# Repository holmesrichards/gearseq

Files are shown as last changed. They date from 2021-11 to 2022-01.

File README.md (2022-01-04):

# G.E.A.R. Sequencer

This is a voltage controlled trigger sequencer or, perhaps a better term, trigger sequence generator. It can function as a Euclidean rhythm generator, but it can also create other rhythms via different means. It is designed in Kosmo format, though it can presumably be adapted to any other format capable of supplying enough positive voltage for 5 V voltage regulators.

## What it does

Rather than sending triggers in a sequence that is completely specified by the user, the G.E.A.R. Sequencer creates sequences based on user specified parameters.

It offers a choice of four algorithms:

* **G**ap sequence
* **E**uclidean sequence
* **A**DC sequence
* **R**andom sequence

(Hence the name G.E.A.R. Sequencer.) Each algorithm is governed by up to four parameters whose values the user can dial in on potentiometers, or they can be set and dynamically altered using control voltages.

Within limits of program memory and programmer sanity, there is no reason more algorithms could not be added, but these are the four implemented so far.

## Algorithms

**Euclidean sequencing** is familiar and I won't go into the details here — see [http://cgm.cs.mcgill.ca/~godfried/publications/banff-extended.pdf](http://cgm.cs.mcgill.ca/~godfried/publications/banff-extended.pdf) if you need them. The sequence pattern is determined by two parameters: Repetition period (*P*) and number of triggers (*T*). The algorithm distributes the *T* triggers as uniformly as possible among the *P* sequence steps. A third parameter, the offset (*O*), governs not the pattern itself but where the pattern starts/stops relative to where the period starts/stops.

A more novel algorithm is the **gap sequence,** based on the procedure underlying linear scales in tuning theory and the [Three-gap Theorem](https://en.wikipedia.org/wiki/Three-gap_theorem) in mathematics — not that you need to know that. I'm not aware of any prior use of this idea for trigger sequencing although I would be quite surprised if no one else has done it before. In a gap sequence the pattern is defined by three parameters: *P*, *T*, and the generator (*G*). For a given *P* and *T* there is exactly one Euclidean sequence, but there are up to *P*/2 gap sequences corresponding to different generators. Again, the position of the sequence start relative to the period can be specified by *O*. You can find details of the algorithm [here](Docs/gap_sequence.md).

An **ADC sequence** uses a pattern based on digitization of an analog control voltage. You specify *P* and a value to digitize, *V*, as well as, again, *O*. The sequence pattern is the first *P* bits in the digitization of *V*. This is similar to something the Barton Musical Circuits BMC006 Voltage To Rhythm Converter does (though the BMC006 does a lot more with the idea).

A **random sequence** is fairly self explanatory. For a given *P* and *T*, the algorithm distributes *T* triggers randomly within *P* steps. The random pattern is then repeated indefinitely, offset by *O* as with the other types, until a new sequence is requested. Another "parameter" is the throw (*Th*). The value of the throw is not used to determine the pattern, but if it changes, a new random pattern will be chosen.

## Current draw
28 mA +12 V, 0 mA -12 V

## Photos

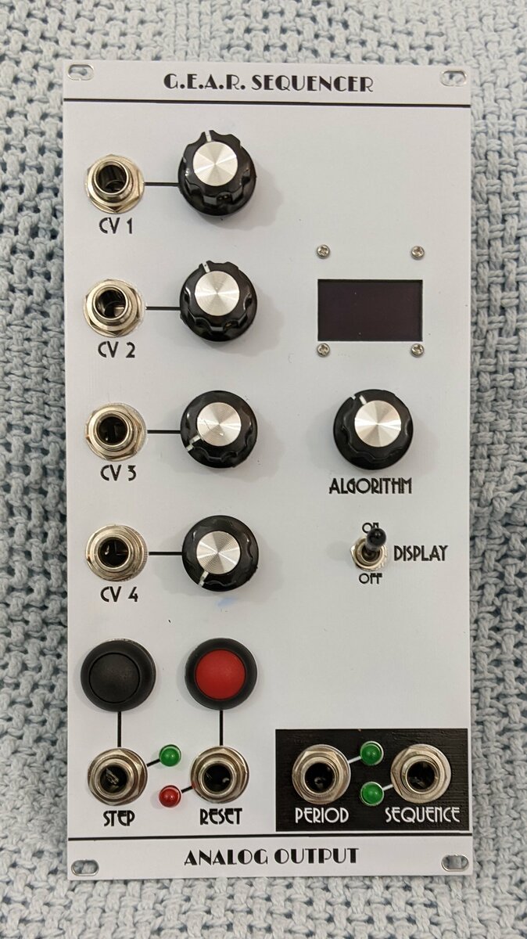
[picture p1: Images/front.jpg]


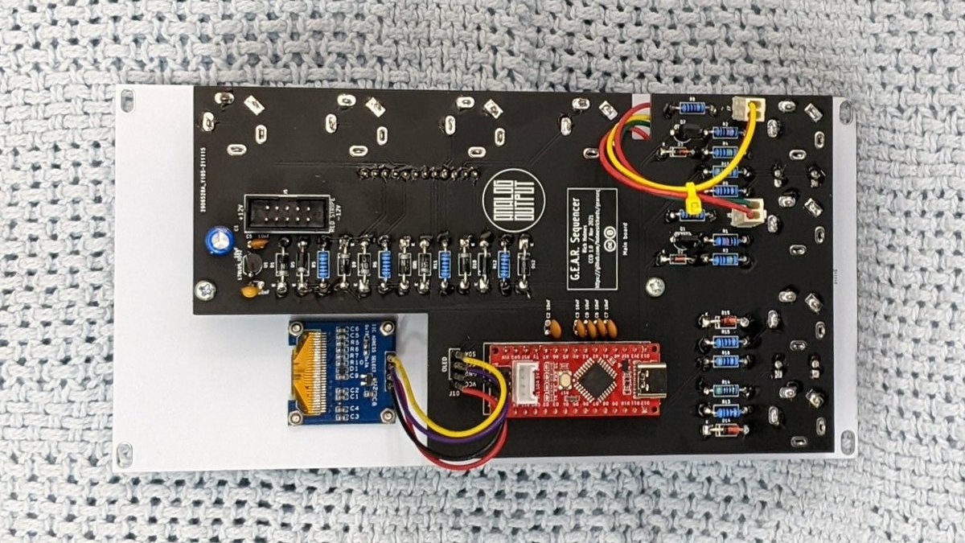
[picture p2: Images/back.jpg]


## Documentation

* [Schematic](Docs/gearseq.pdf)
* PCB layout: [front](Docs/gearseq_layout_front.pdf), [back](Docs/gearseq_layout_back.pdf)
* [BOM](Docs/gearseq_bom.md)
* [Build notes](Docs/build.md)
* [Implementation details](Docs/implementation.md)
* [Gap sequence algorithm](Docs/gap_sequence.md)
* [Usage notes](Docs/usage_notes.md)

## GitHub repository

* [https://github.com/holmesrichards/gearseq](https://github.com/holmesrichards/gearseq)

## Submodules

This repo uses submodules aoKicad and Kosmo_panel, providing libraries needed for KiCad. To clone:

```
git clone git@github.com:holmesrichards/gearseq.git
git submodule init
git submodule update
```

Alternatively do

```
git clone --recurse-submodules git@github.com:holmesrichards/gearseq.git
```

Or if you download the repository as a zip file, you must also click on the "aoKicad" and "Kosmo\_panel" links on the GitHub page (they'll have "@ something" after them) and download them as separate zip files which you can unzip into this repo's aoKicad and Kosmo\_panel directories.

If desired, copy the files from aoKicad and Kosmo\_panel to wherever you prefer (your KiCad user library directory, for instance, if you have one). Then in KiCad, add symbol libraries 

```
aoKicad/ao_symbols
Kosmo_panel/Kosmo
```
and footprint libraries 
```
aoKicad/ao_tht
Kosmo_panel/Kosmo_panel.
```

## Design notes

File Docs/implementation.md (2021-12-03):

# G.E.A.R. Sequncer implementation details

The algorithm pot is used to select the algorithm. Turn it hard left for "None" (no output), right for random, and in between for gap, Euclidean, or ADC.

The parameters — up to four of them — can be selected using the other pots and the associated control voltage inputs. With no cable plugged in a pot can be used to select a parameter manually; with a cable plugged in, the CV attenuated by the pot (in the range 0 to 5 V) determines the parameter.

If a parameter value is changed, or a different algorithm is selected, the change takes effect at the start of the next period. If you can't wait, use the Reset button.

Algorithm choice, parameter values, and the trigger pattern are shown on an OLED display. Normally it displays the values currently in use, and if a parameter has a different value requested than the current one (either because the current one has not been updated yet, or because the requested value is outside the current valid range) it is shown in brackets. While adjusting a pot, the display switches to showing the values that will go into effect at the next period if no further changes occur. As visual hints you are looking at future instead of present values, there is an asterisk in the upper left corner, and the trigger pattern is shown at the bottom with Xs and dots (representing trigger and no trigger) instead of the normal Os and dashes.

Other inputs are a clock, which steps the sequencer, and a reset pulse, which sends the sequence back to its start on the next clock. There are buttons for manual stepping and resetting too. Outputs are the sequence itself and a pulse at the start of each period. (If you don't need a trigger sequence but are hurting for clock dividers, just use the period output for any division up to 32!)

Internally, an Arduino Nano (clone) collects the clock, reset, and CV inputs, reads the pots, updates the OLED, calculates the sequence, and sends the sequence and period pulses out. It works pretty hard. Be nice to it.

## Pot assignments

### Pot+CV 1 and 4

Pot+CV 1 always determines the period *P* and pot+CV 4 determines the offset *O*. 

### Pot+CV 2

For all but the ADC algorithm, pot+CV 2 determines the number of triggers *T*. For ADC, it is the value to be digitized, *V*. 

### Pot+CV 3

Pot+CV 3's function varies between algorithms:

* Gap: Generator *G*.
* Euclidean or ADC: Not used.
* Random: Throw *Th*. Not used in determining the pattern, but a change in this parameter causes a new sequence to be generated.

### Parameter ranges

Parameters may be requested within ranges as follows. The (dynamic) valid range for a parameter may be smaller than the (static) range of values that can be requested. If the requested value is outside the valid range, it will be adjusted to a valid value.

|Pot|Parameter|Algorithm|Requested range|Valid range|
|----|----|----|----|----|
|1|*P*|G,E,A,R|2–32|ADC: 2–10; others: 2–32|
|2|*T*|G,E,R|0–32|0–*P* *|
|2|*V*|A|0–1023|0–1023|
|3|*G*|G|1–16|1–*P*/2|
|3|*Th*|R|0–31|0–31|
|4|*O*|G,E,A,R|0–31|0–*P*-1

The limit of 32 for *P*, and the related upper limits for *T*, *G*, and *O*, can be changed in software. Reducing them should be trivial; increasing them would involve some coding. For ADC the limits of 10 for *P* and 1023 for *V* can't be increased; you could decrease them, though. (They're related: *V_max* = 2^*P_max* - 1.)

\* **Note:** For the gap algorithm, the actual maximum number of triggers may be some fraction of *P* (depending on *G*), in which case the requested value of *T* will be truncated if it is larger.

## Dependencies

The following Arduino libraries must be installed:

* DirectIO [https://github.com/mmarchetti/DirectIO](https://github.com/mmarchetti/DirectIO)
* u8g2 [https://github.com/olikraus/u8g2/wiki](https://github.com/olikraus/u8g2/wiki)

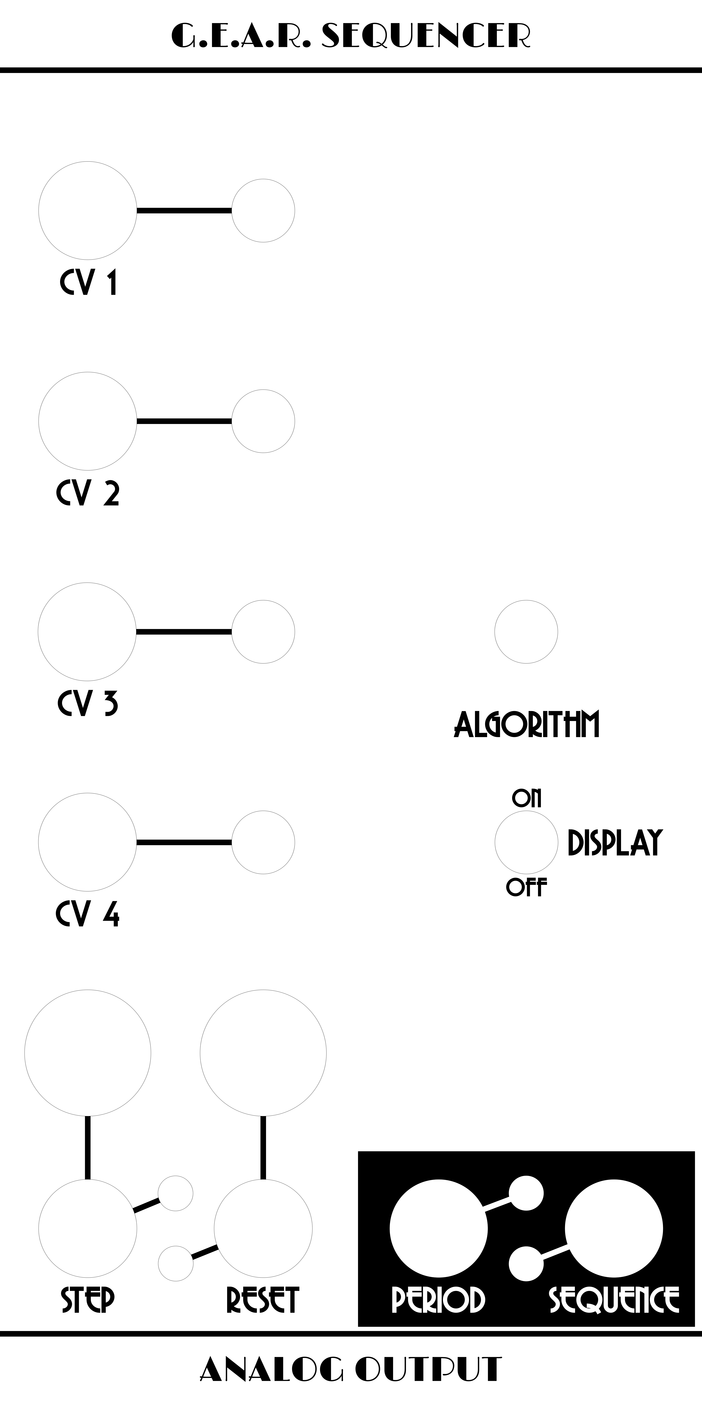
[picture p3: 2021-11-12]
Images/gearseq_panel_art.png

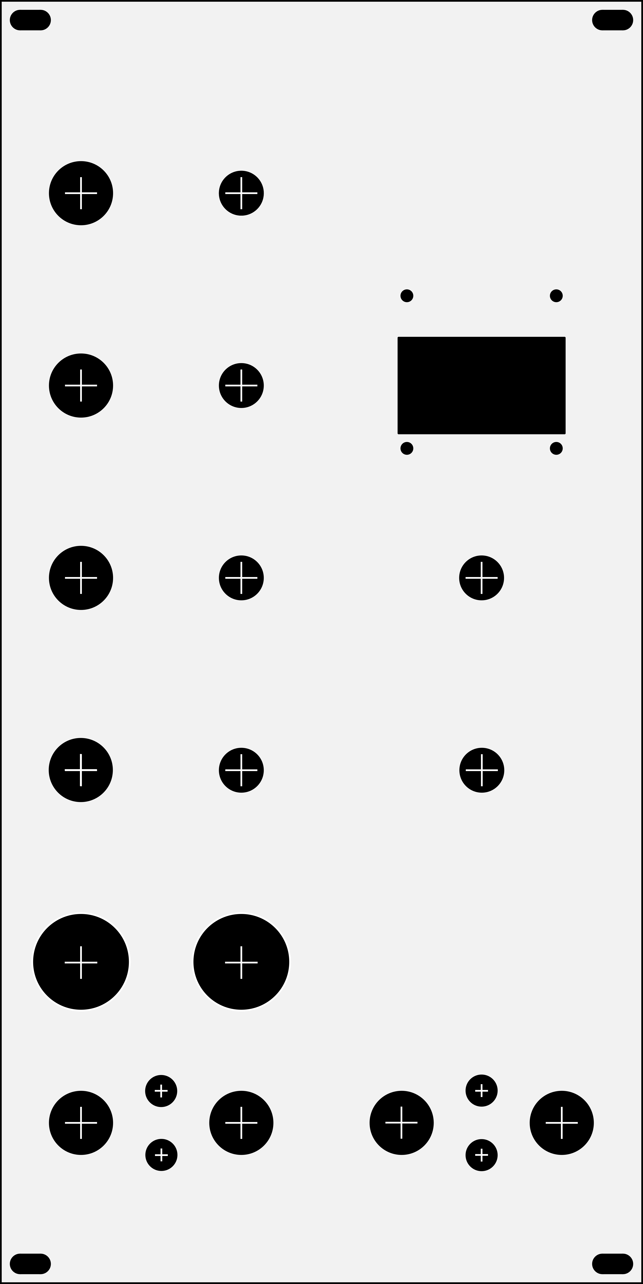
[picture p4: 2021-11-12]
Images/gearseq_panel_holes.png

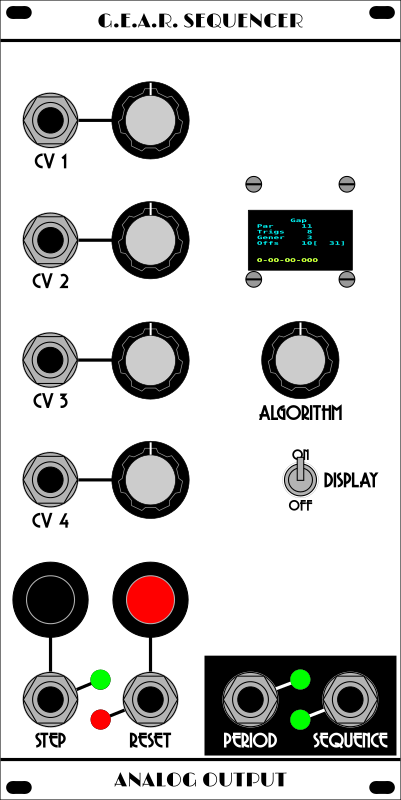
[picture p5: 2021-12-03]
Images/gearseq_panel.png

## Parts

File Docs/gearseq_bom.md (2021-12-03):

# gearseq.sch BOM

Thu 02 Dec 2021 06:33:21 PM EST

Generated from schematic by Eeschema 5.1.12-84ad8e8a86~92~ubuntu20.04.1

**Component Count:** 75

| Refs | Qty | Component | Description | Vendor | SKU |
| ----- | --- | ---- | --- | ---- | ---- |
| A1 | 1 | Arduino_Nano_v3.x | Arduino Nano v3.x |  Tayda | A-2864 |
| C1 | 1 | 10uF | Electrolytic capacitor | Tayda | A-4349 |
| C2, C3, C5, C6, C7, C8 | 6 | 10nF | Ceramic capacitor | Tayda | A-962 |
| C4 | 1 | 330nF | MCC capacitor | Tayda | A-319 |
| D1, D4, D5, D6, D7, D10, D11, D12, D13 | 9 | 1N5817 | Schottky Barrier Rectifier Diode, DO-41 | Tayda | A-159 |
| D2, D3 | 2 | 1N4148 | Standard switching diode, DO-35 | Tayda | A-157 |
| D8 | 1 | LED_red | Light emitting diode | Tayda | A-1554 |
| D9, D16, D17 | 3 | LED_green | Light emitting diode | Tayda | A-1553 |
| D14, D15 | 2 | 1N4733A | 5.1 V 1300mW Zener Diode, DO-41 | Tayda | A-169 |
| J1, J2, J8, J9 | 4 | AudioJack2_SwitchT | Audio Jack, 2 Poles (Mono / TS), Switched T Pole (Normalling) | Tayda | A-1121 |
| J3, J4, J12, J13 | 4 | AudioJack2 | Audio Jack, 2 Poles (Mono / TS) | Tayda | A-1121 |
| J5 | 1 | Synth_power_2x5 | Shrouded header 2.54 mm 2x5 | Tayda | A-2939 |
| J6, J7 | 2 | 2_pin_Molex_header | KK254 Molex header | Tayda | A-804 |
| J10 | 1 | Conn_01x04 | 2.54 mm 1x4 pin header |  |  |
| J11 | 1 | Conn_01x12 | 2.54 mm 1x12 pin header |  |  |
| J14 | 1 | Conn_01x12 | 2.54 mm 1x12 pin socket |  |  |
| J15, J16 | 2 | 2_pin_Molex_connector | KK254 Molex connector | Tayda | A-826 |
| OLED1 | 1 | OLED_128X64\* | 128 x 64 OLED module, I2C | AliExpress, eBay, etc. |  |
| Q1, Q2 | 2 | 2N3904 | Small Signal NPN Transistor, TO-92 | Tayda | A-111 |
| R1, R2 | 2 | 100k | Resistor | Tayda |  |
| R3, R4 | 2 | 1M | Resistor | Tayda |  |
| R5, R6, R11, R12, R13, R15 | 6 | 1k | Resistor | Tayda |  |
| R7, R8 | 2 | 10k | Resistor | Tayda |  |
| R9, R10, R14, R16 | 4 | RL\*\* | Resistor | Tayda |  |
| RV1 | 1 | 10k | 9 mm vertical board mount potentiometer\*\*\* | Tayda |  |
| RV2, RV3, RV4, RV5 | 4 | 100k | 9 mm vertical board mount potentiometer\*\*\* | Tayda |  |
| RV6 | 1 | 10k | 16 mm vertical board mount potentiometer\*\*\* | Tayda |  |
| RV7, RV8, RV9, RV10 | 4 | 100k | 16 mm vertical board mount potentiometer\*\*\* | Tayda |  |
| SW1 | 1 | SW_Push_black | Push button switch, normally open | Tayda | A-3487 |
| SW2 | 1 | SW_Push_red | Push button switch, normally open | Tayda | A-3486 |
| SW3 | 1 | SW_SPST | SPST toggle switch | Tayda | A-3186 (SPDT, use as SPST) |
| U1 | 1 | L78L05_TO92 | Positive 100mA 30V Linear Regulator, Fixed Output 5V, TO-92 | Tayda | A-176 |
| | 1 | socket | 30 pin DIP socket, or 2x 2.54 mm 1x15 pin socket, for Arduino | | |
| | 4 | jumpers | Female-female Dupont jumpers, 10 cm | | |
| | 5 | knobs | | | |
| | 4 | screws | M2 8 mm screws | | |
| | 8 | nuts | M2 nuts | | |
| | 4 | screws | M3 6 mm screws | | |
| | 2 | spacers | M3 10 mm spacers | | |

\* This can be MC096VX or MC096GX or other compatible OLED. Note these have VCC and GND in the opposite order on their header. 

\*\* Resistor for LED current limit and brightness; use whatever value you prefer for your LEDs. See [build notes](build.md).

\*\*\* Fit either 9 mm or 16 mm potentiometers (not both)

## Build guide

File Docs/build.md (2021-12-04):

# G.E.A.R. Sequencer build and software notes

The build is pretty straightforward. Note there are no socketed ICs, but you should socket the Nano. Use a large DIP socket (normally you'd find 32 pin sockets, not 30, but you can bend or cut away two pins) or two 1x15 pin sockets. In the latter case put a Nano in the sockets (use a dead one if you have one) before soldering to make sure they stay aligned.

Also note this module makes no use of -12 V, and +12 V is used only to feed 5 V regulators — the one on the Nano, and an external one. So this design should be usable with any kind of power supply that can power a 5 V regulator, including a 9 V battery. Presumably. I haven't tried it!

## Errata

One sort-of error on the first run PCB: C4 (330 µF) has the wrong footprint, with the holes too close together. Not really a problem, just bend the leads toward each other on your capacitor. You can use an electrolytic here if you'd rather, just make sure the negative (-) lead is in the hole closer to D1.

## Construction

The two circuit boards are connected with a 12-pin header/socket pair, and with two 10 mm M3 spacers, secured with 6 mm M3 screws through the holes in the PCBs.

Pay attention to what goes on what side. On the main PCB, the jacks, LEDs, and 12-pin header go on one side, everything else on the other. On the pots board the pots and toggle switch go on one side, the 12-pin socket goes on the other. That should be evident from the silkscreen.

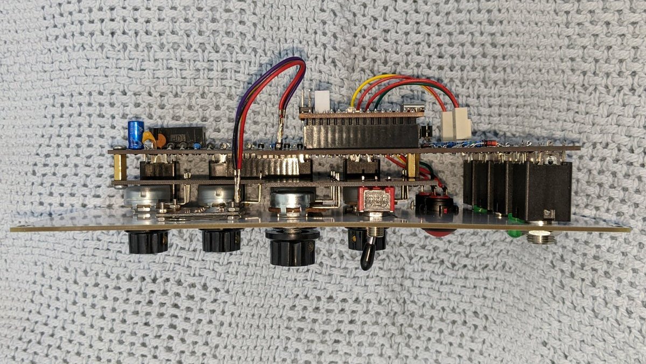
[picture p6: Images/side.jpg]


## Panel components

There are footprints provided for both 9 mm and 16 mm vertical board mount pots. Buy and mount only one or the other! (You can mix and match between pot positions.)

Three of the LEDs are marked as "green" and one "red"; of course you can use whatever colors you prefer. Associated with them are four resistors with value shown as "RL". Use whatever value works well with your LEDs. Minimum value should be (5-Vf)/Imax where Vf and Imax are the forward voltage and maximum current from the LED datasheet, but you probably will want a larger value for a less blinding brightness. I used regular green LEDs (D9, D16, and D17 for the clock, sequence, and period, respectively) and a superbright red (D8 for reset) from Tayda with 470 Ω resistors for the greens (R10, R14, R16) and 2 kΩ for the red (R9).

As usual with the pots, jacks, LEDs, and toggle switch, put them in position; place the front panel over them and fasten it down with nuts on some of the panel components; then and only then solder them.

The OLED can be MC096VX or MC096GX or other compatible OLED. Note these have VCC and GND in the opposite order on their header, so reverse their order with the jumpers if you need to. You can get these displays in white, blue, or blue and yellow versions; any of these will work. The reason it is mounted upside down is to have the yellow stripe at the bottom, if you use a blue and yellow version, to highlight the trigger pattern on the display. The OLED should be mounted to the front panel using M2 screws. I secured four screws to the panel with nuts, then put the OLED on and secured it with four more nuts. 

The OLED and the push button switches connect to the PCB via wires. You can solder the wires directly to the PCB, but for the push buttons I recommend fitting Molex connectors to the wires and Molex headers on the board. Route the wires through the slot in the PCB. For the OLED I mounted a 1x4 pin header on the PCB and used short female-female Dupont jumpers to connect it up. 

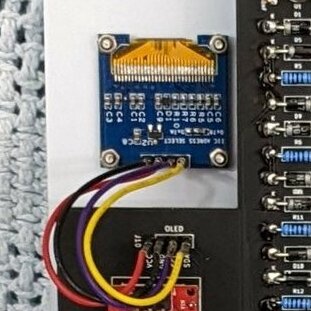
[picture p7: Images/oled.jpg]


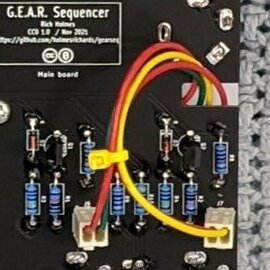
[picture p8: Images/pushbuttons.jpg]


## Software

Upload the gearSeqSketch.ino sketch (in the folder Software/gearSeqSketch). The software requires you install two libraries:

* DirectIO [https://github.com/mmarchetti/DirectIO](https://github.com/mmarchetti/DirectIO)
* u8g2 [https://github.com/olikraus/u8g2/wiki](https://github.com/olikraus/u8g2/wiki)

Upload the software to the Nano and then unplug the USB cable before connecting to +12 V power.

Also in the Software folder is a Python script, gearEuclid.py. This is not needed for anything, and does not work with the module, it just demonstrates the Gap and Euclidean algorithms in a probably more readable form than the Arduino sketch. You can run it on the command line of your computer with four parameters as arguments and see what each algorithm produces for a trigger pattern. For instance, try: `python3 gearEuclid.py  16 5 7 2`.

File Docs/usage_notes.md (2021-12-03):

# G.E.A.R. Sequencer usage notes

- The code uses interrupts and the DirectIO library to keep it responsive to clock pulses, but handling the OLED is slow and the response to parameter changing could potentially become sluggish if changes happen at high rates. Once you have a patch set up and running, the display might not be very useful, so you can turn it off using the front panel toggle switch, and that should improve responsiveness (and be less distracting).

- For most of the parameters, a fairly large change in potentiometer position or CV is required to make the parameter change. For the ADC algorithm, the Value parameter is an exception, since it can take any of 1024 values. Even so this isn't likely to be a problem if the period is short (say, under 8). But with period 10, even a 5 millivolt change in the CV will change the trigger pattern. This is part of why the Nano runs on its own on-board regulator while the OLED is powered by an off-board one, because that reduces noise on the CV inputs that can wreak havoc with the ADC Value parameter. If you plug in a CV and find Value is jumping around erratically you probably have noise on that CV. One thing you can try is running the CV through a low pass filter or lag processor to smooth out high frequency noise.

- Unlike with the Euclidean and random algorithms, where changing *T* by one can give a completely different pattern, incrementing *T* in the gap algorithm simply converts one non-trigger step in the pattern to a trigger step. This is something that can be usefully exploited with a slowly varying control voltage, gradually adding or removing triggers from the sequence pattern.

- When *G* is an even divisor of *P* in the gap algorithm, the maximum number of triggers is only a fraction of *P*. (Specifically, *P* divided by the greatest common divisor of *P* and *G*.) So periods with lots of divisors, such as 12, offer fewer possibilities than prime periods, like 11 or 13. To get more possibilities for 12 (for instance), you can "cheat": set *P* to 13. Now you can get as many triggers as you want with *G* being any number from 1 through 6. Then use an external clock divider to pulse the reset input every 12 clock pulses.

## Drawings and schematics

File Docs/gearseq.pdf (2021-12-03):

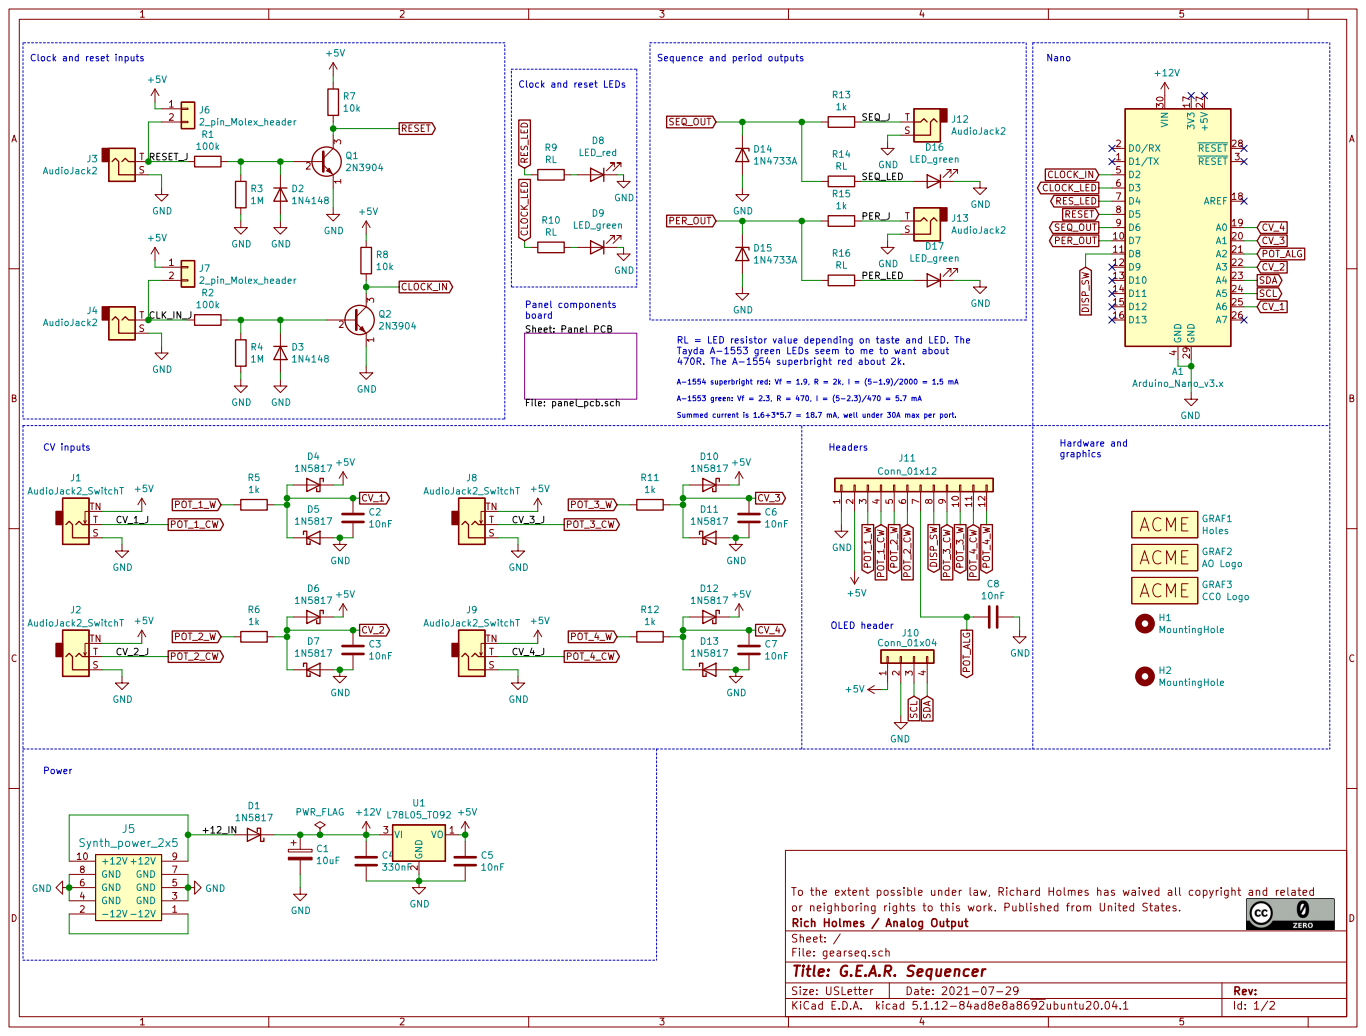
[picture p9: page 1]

Summed current is 1.6+3*5.7 = 18.7 mA, well under 30A max per port. Clock and reset LEDs CV inputs

RL = LED resistor value depending on taste and LED. The
Tayda A-1553 green LEDs seem to me to want about
470R. The A-1554 superbright red about 2k. OLED header A-1554 superbright red: Vf = 1.9, R = 2k, I = (5-1.9)/2000 = 1.5 mA

To the extent possible under law, Richard Holmes has waived all copyright and related
or neighboring rights to this work. Published from United States.
File: gearseq.sch Sheet: / Rich Holmes / Analog Output

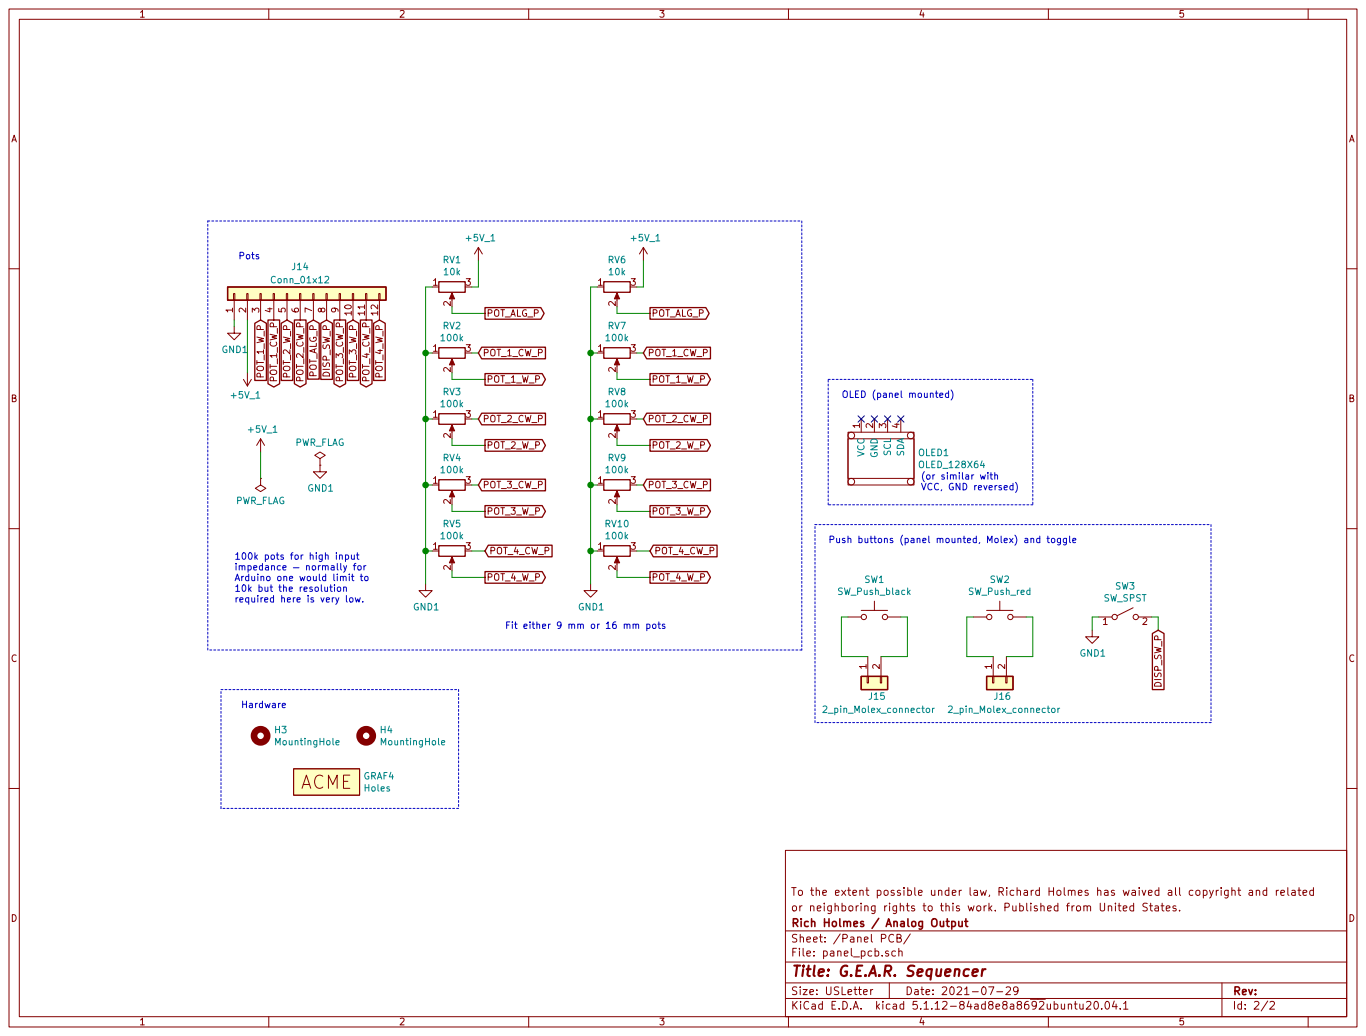
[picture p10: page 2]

100k pots for high input
impedance normally for Arduino one would limit to

To the extent possible under law, Richard Holmes has waived all copyright and related
or neighboring rights to this work. Published from United States.
File: panel_pcb.sch Sheet: /Panel PCB/ Rich Holmes / Analog Output

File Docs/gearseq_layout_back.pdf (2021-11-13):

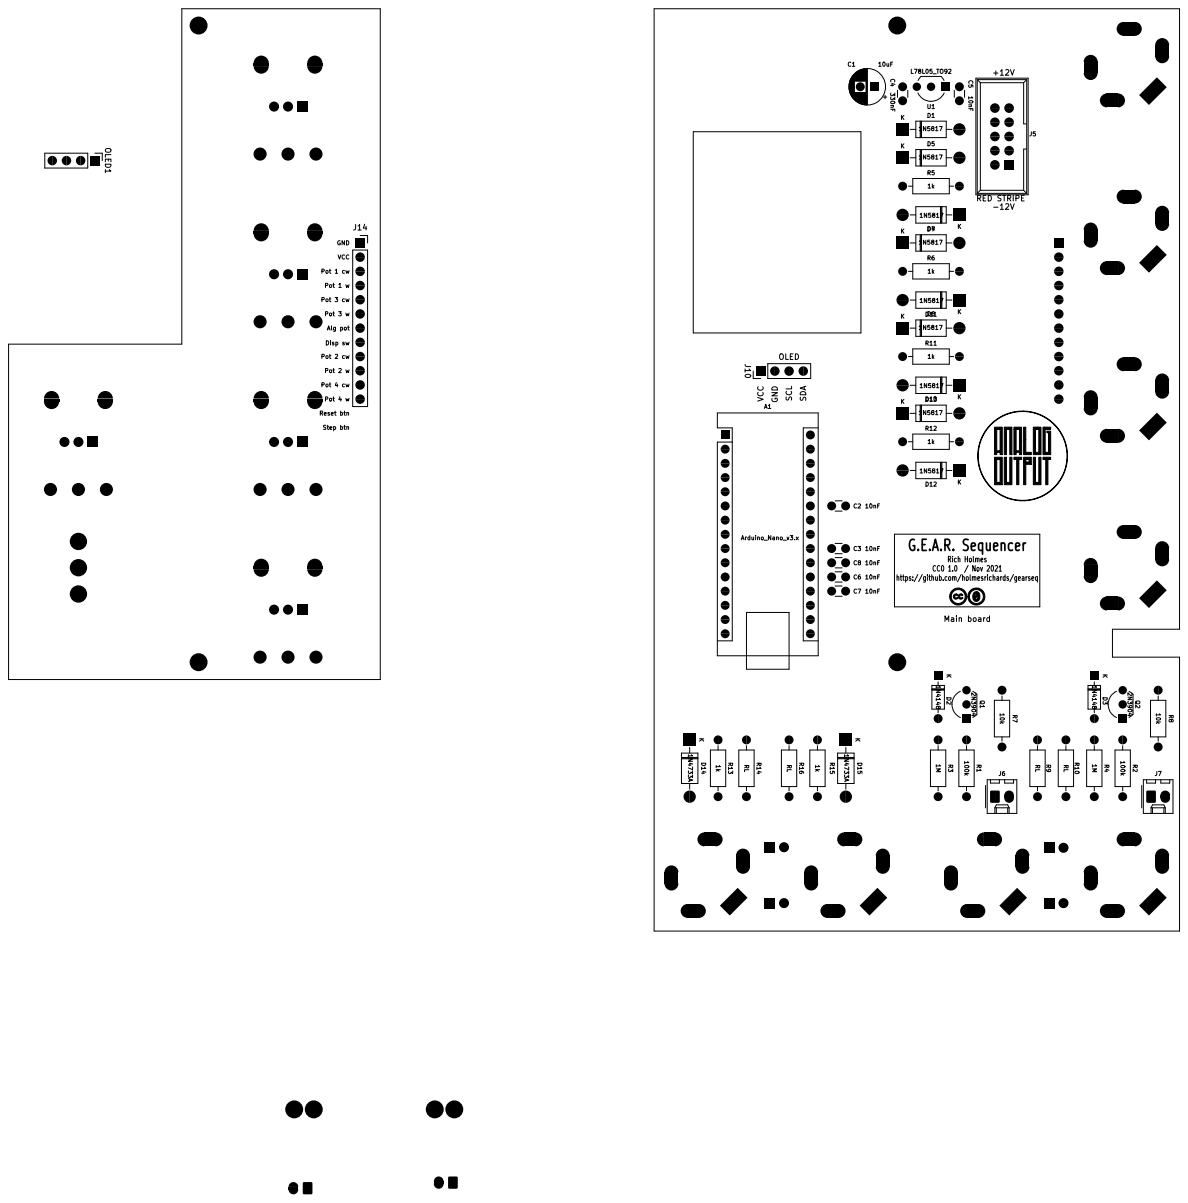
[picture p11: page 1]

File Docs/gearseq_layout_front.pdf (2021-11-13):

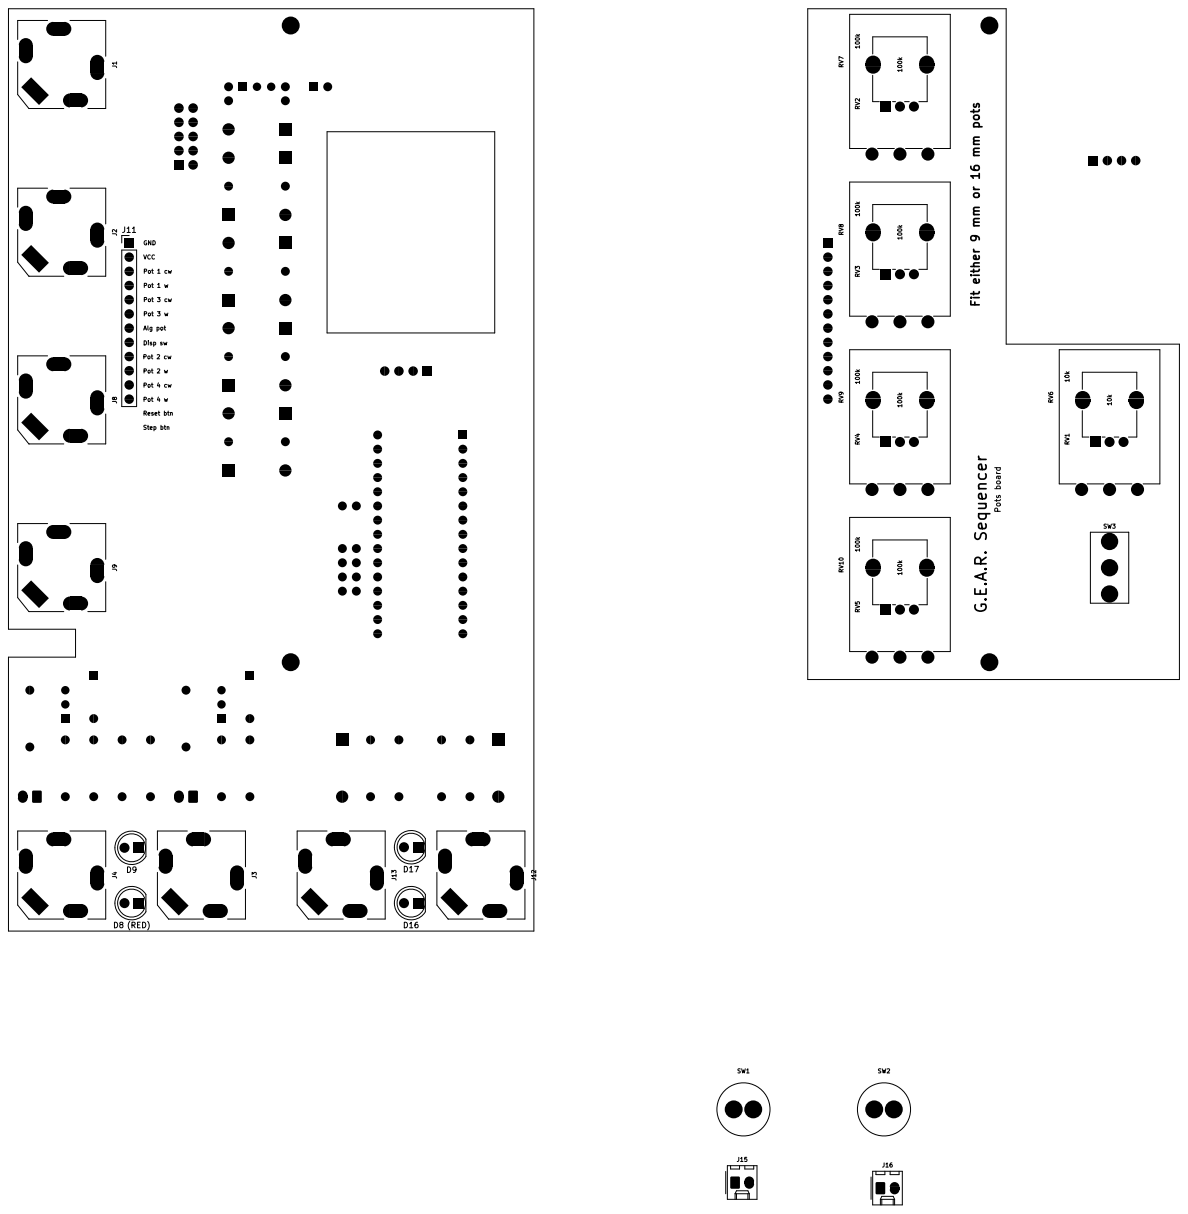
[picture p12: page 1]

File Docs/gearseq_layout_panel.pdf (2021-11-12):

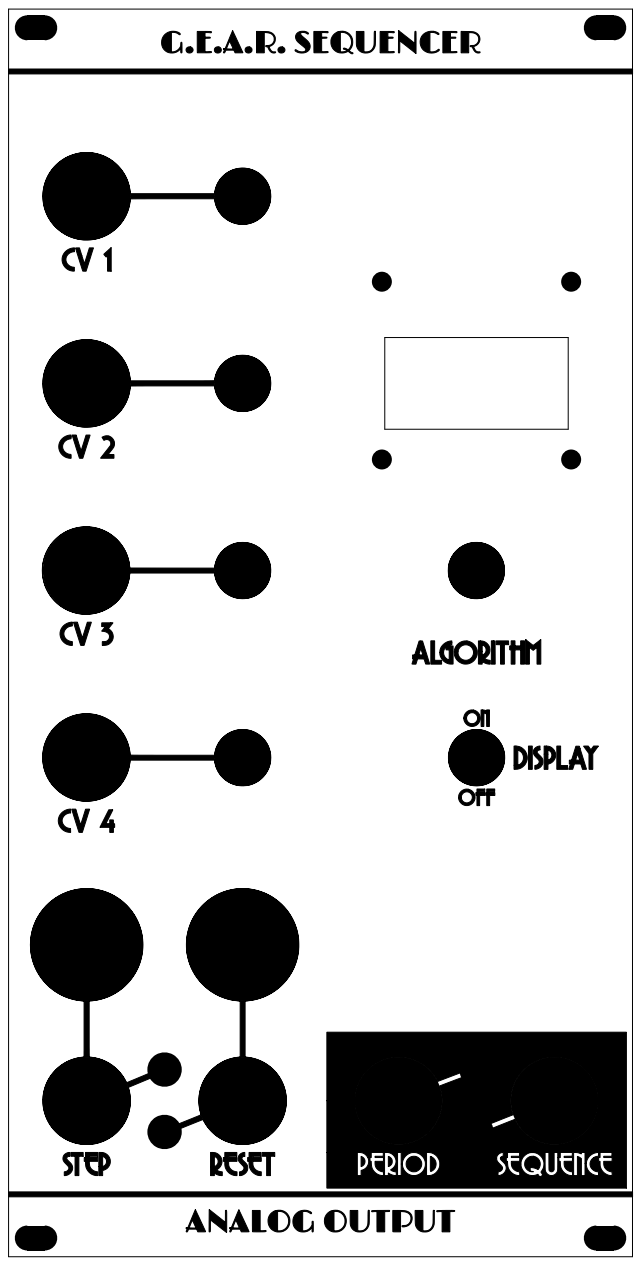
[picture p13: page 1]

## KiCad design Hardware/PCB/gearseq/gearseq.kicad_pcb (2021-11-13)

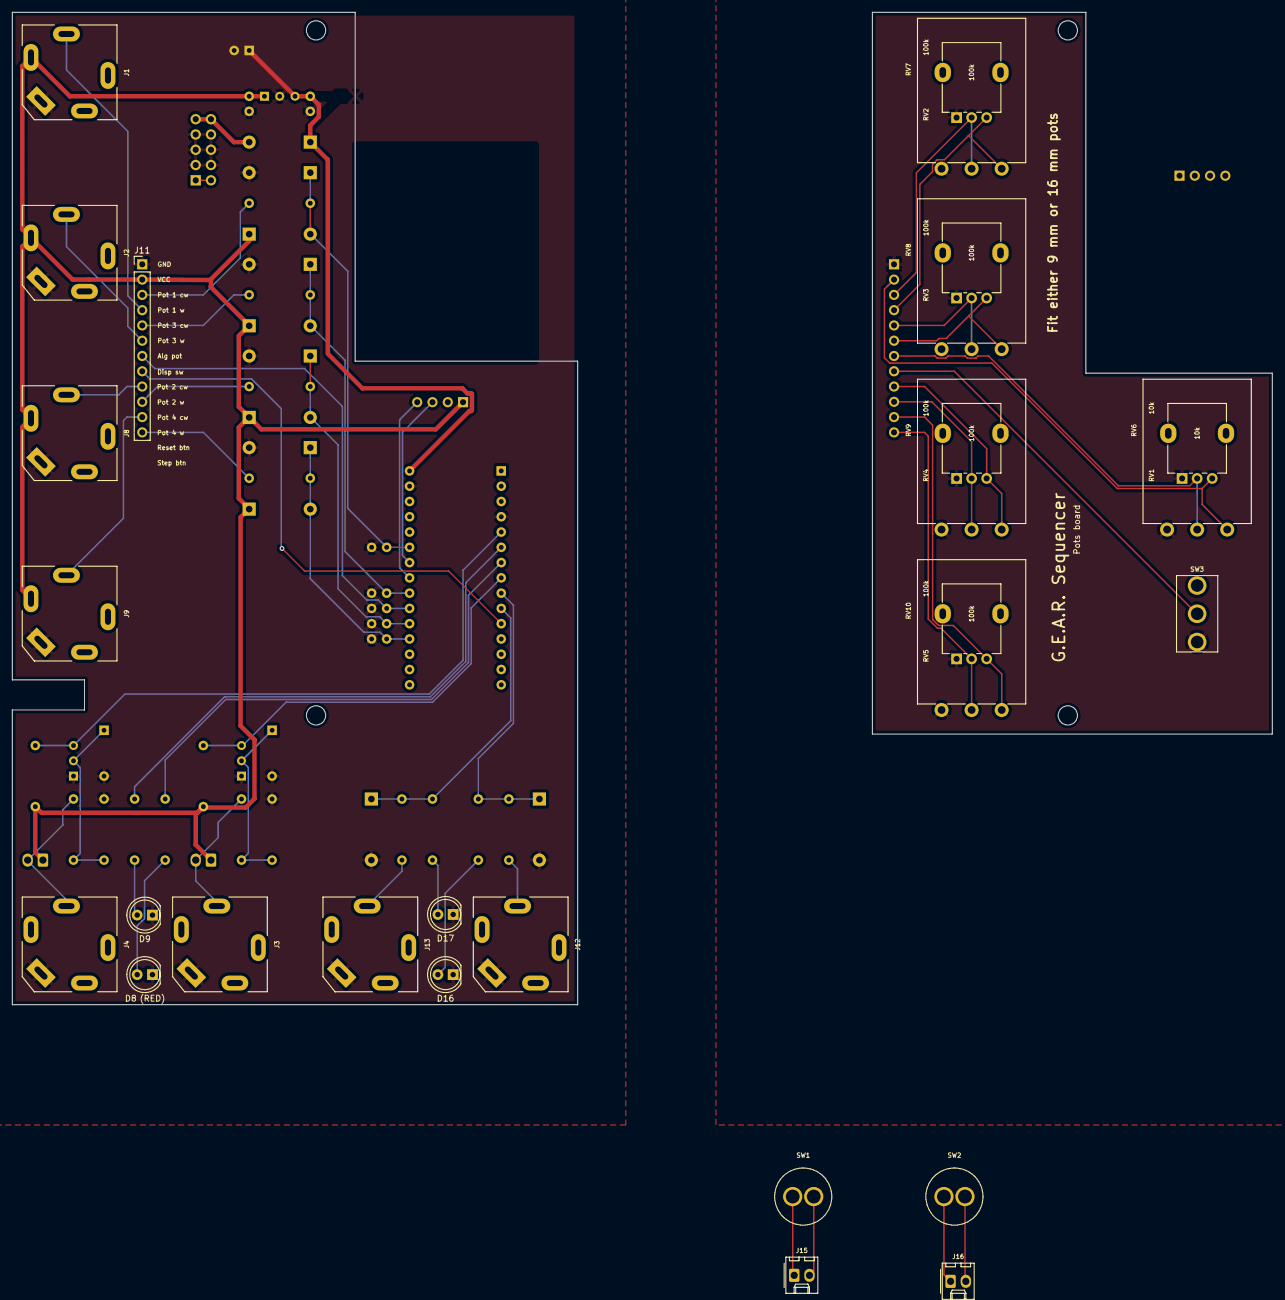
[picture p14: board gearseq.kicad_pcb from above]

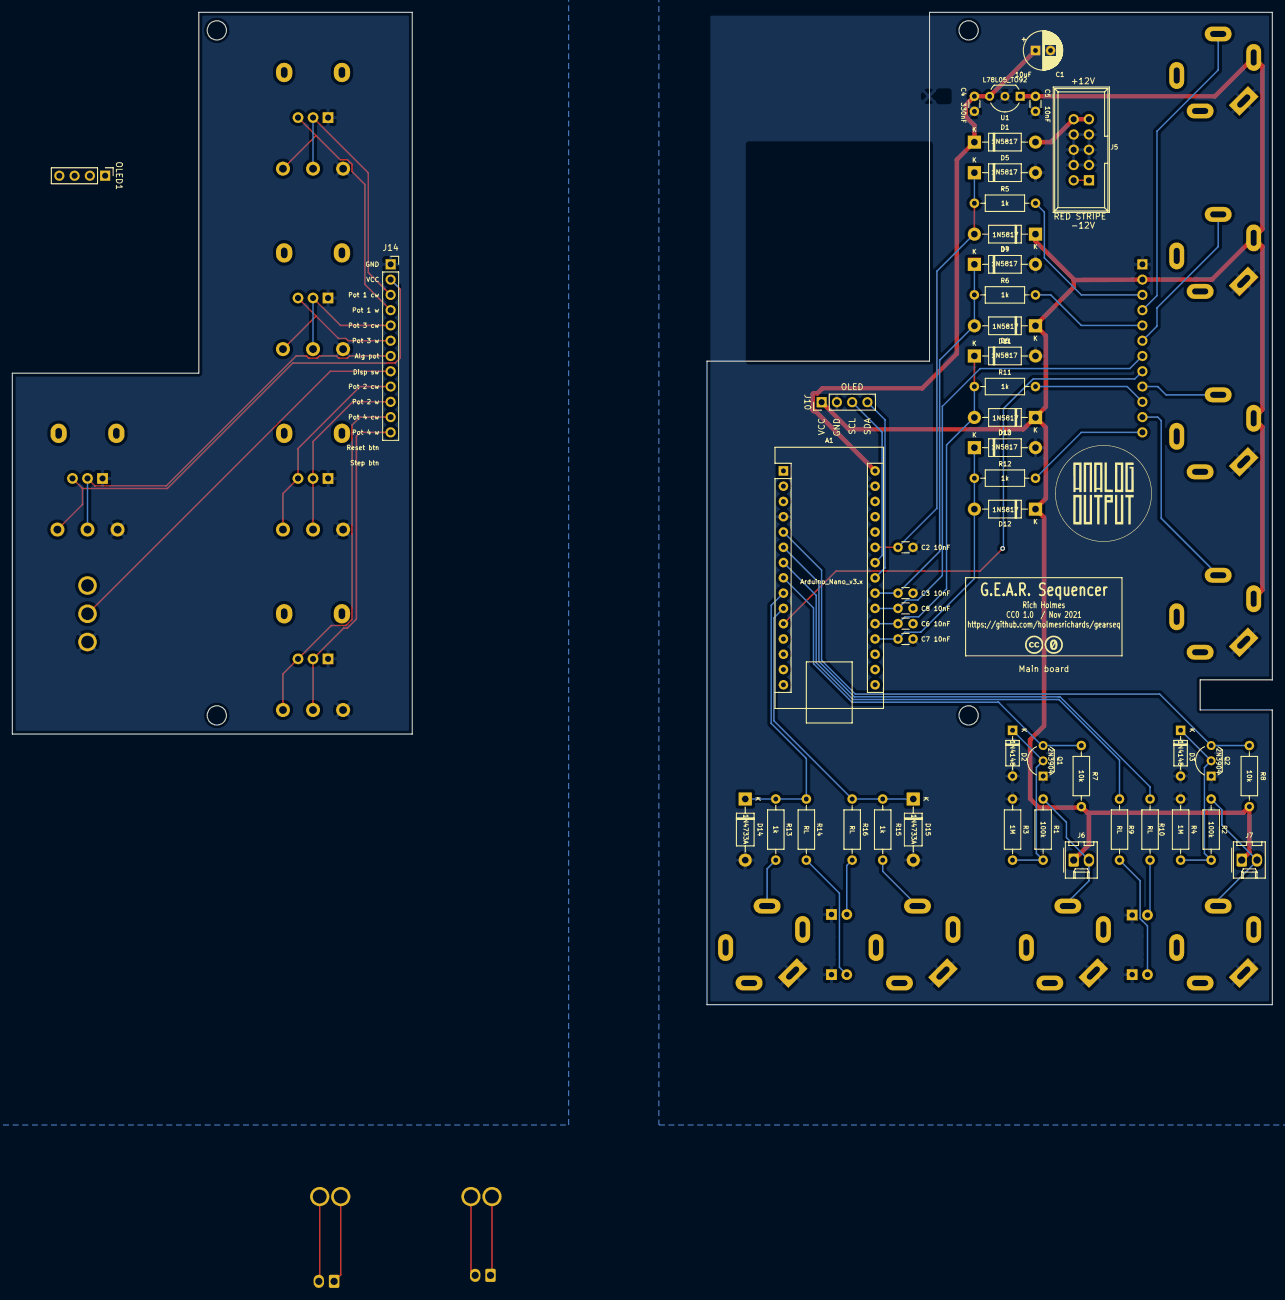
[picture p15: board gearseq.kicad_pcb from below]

Board: 2 copper layers, 209.5 x 165.0 mm, 83 parts (49 on the bottom side), 53 nets.

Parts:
A1: Arduino_Nano_v3.x; Arduino_Nano
C1: 10uF; CP_Radial_D6.3mm_P2.50mm
C2, C3, C5, C6, C7, C8: 10nF; C_Disc_D3.0mm_W1.6mm_P2.50mm
C4: 330nF; C_Disc_D3.0mm_W1.6mm_P2.50mm
D1, D4, D5, D6, D7, D10, D11, D12, D13: 1N5817; D_DO-41_SOD81_P10.16mm_Horizontal
D2, D3: 1N4148; D_DO-35_SOD27_P7.62mm_Horizontal
D8: LED_red; LED_D5.0mm
D9, D16, D17: LED_green; LED_D5.0mm
D14, D15: 1N4733A; D_DO-41_SOD81_P10.16mm_Horizontal
GRAF1, GRAF4: Holes; gearseq_panel_holes
GRAF2: AO Logo; analogoutput
GRAF3: CC0 Logo; CC0_logo
H1, H2, H3, H4: MountingHole; MountingHole_3.2mm_M3
J1, J2, J8, J9: AudioJack2_SwitchT; Jack_6.35mm_PJ_629HAN_slots
J3, J4, J12, J13: AudioJack2; Jack_6.35mm_PJ_629HAN_slots
J5: Synth_power_2x5; Power_Header
J6, J7: 2_pin_Molex_header; Molex_KK-254_AE-6410-02A_1x02_P2.54mm_Vertical
J10: Conn_01x04; PinHeader_1x04_P2.54mm_Vertical
J11: Conn_01x12; PinHeader_1x12_P2.54mm_Vertical
J14: Conn_01x12; PinSocket_1x12_P2.54mm_Vertical
J15, J16: 2_pin_Molex_connector; Molex_KK-254_AE-6410-02A_1x02_P2.54mm_Vertical
OLED1: OLED_128X64; PinHeader_1x04_P2.54mm_Vertical
Q1, Q2: 2N3904; TO-92_Inline_Wide
R1, R2: 100k; R_Axial_DIN0207_L6.3mm_D2.5mm_P10.16mm_Horizontal
R3, R4: 1M; R_Axial_DIN0207_L6.3mm_D2.5mm_P10.16mm_Horizontal
R5, R6, R11, R12, R13, R15: 1k; R_Axial_DIN0207_L6.3mm_D2.5mm_P10.16mm_Horizontal
R7, R8: 10k; R_Axial_DIN0207_L6.3mm_D2.5mm_P10.16mm_Horizontal
R9, R10, R14, R16: RL; R_Axial_DIN0207_L6.3mm_D2.5mm_P10.16mm_Horizontal
RV1: 10k; Potentiometer_Alpha_RD901F-40-00D_Single_Vertical_centered
RV2, RV3, RV4, RV5: 100k; Potentiometer_Alpha_RD901F-40-00D_Single_Vertical_centered
RV6: 10k; Potentiometer_Alpha_16mm_Single_Vertical
RV7, RV8, RV9, RV10: 100k; Potentiometer_Alpha_16mm_Single_Vertical
SW1: SW_Push_black; Push_button_A-5050
SW2: SW_Push_red; Push_button_A-5050
SW3: SW_SPST; SPDT-toggle-switch-1M-series
U1: L78L05_TO92; TO-92_Inline_Wide

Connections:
+5V: C5.1, D4.1, D6.1, D10.1, D12.1, J1.TN, J2.TN, J6.1, J7.1, J8.TN, J9.TN, J10.1, J11.2, R7.1, R8.1, U1.1
+5V_1: J14.2, RV1.3, RV6.3
+12V: A1.30, C1.1, C4.1, D1.1, U1.3
/+12_IN: D1.2, J5.9, J5.10
/CLK_IN_J: J4.T, J7.2, R2.2
/PER_J: J13.T, R15.1
/PER_LED: D17.2, R16.1
/RESET_J: J3.T, J6.2, R1.2
/SEQ_J: J12.T, R13.1
/SEQ_LED: D16.2, R14.1
CLOCK_IN: A1.5, Q2.3, R8.2
CLOCK_LED: A1.6, R10.2
CV_1: A1.25, C2.1, D4.2, D5.1, R5.1
CV_2: A1.22, C3.1, D6.2, D7.1, R6.1
CV_3: A1.20, C6.1, D10.2, D11.1, R11.1
CV_4: A1.19, C7.1, D12.2, D13.1, R12.1
DISP_SW: A1.11, J11.8
DISP_SW_P: J14.8, SW3.2
GND: A1.4, A1.29, C1.2, C2.2, C3.2, C4.2, C5.2, C6.2, C7.2, C8.2, D2.2, D3.2, D5.2, D7.2, D8.1, D9.1, D11.2, D13.2, D14.2, D15.2, D16.1, D17.1, J1.S, J2.S, J3.S, J4.S, J5.3, J5.4, J5.5, J5.6, J5.7, J5.8, J8.S, J9.S, J10.2, J11.1, J12.S, J13.S, Q1.1, Q2.1, R3.2, R4.2, U1.2
GND1: J14.1, RV1.1, RV2.1, RV3.1, RV4.1, RV5.1, RV6.1, RV7.1, RV8.1, RV9.1, RV10.1, SW3.1
unnamed: D2.1, Q1.2, R1.1, R3.1
unnamed: D3.1, Q2.2, R2.1, R4.1
unnamed: D8.2, R9.1
unnamed: D9.2, R10.1
unnamed: J5.1, J5.2
unnamed: J15.1, SW1.1
unnamed: J15.2, SW1.2
unnamed: J16.1, SW2.1
unnamed: J16.2, SW2.2
PER_OUT: A1.10, D15.1, R15.2, R16.2
POT_1_CW: J1.T, J11.4
POT_1_CW_P: J14.4, RV2.3, RV7.3
POT_1_W: J11.3, R5.2
POT_1_W_P: J14.3, RV2.2, RV7.2
POT_2_CW: J2.T, J11.6
POT_2_CW_P: J14.6, RV3.3, RV8.3
POT_2_W: J11.5, R6.2
POT_2_W_P: J14.5, RV3.2, RV8.2
POT_3_CW: J8.T, J11.9
POT_3_CW_P: J14.9, RV4.3, RV9.3
POT_3_W: J11.10, R11.2
POT_3_W_P: J14.10, RV4.2, RV9.2
POT_4_CW: J9.T, J11.11
POT_4_CW_P: J14.11, RV5.3, RV10.3
POT_4_W: J11.12, R12.2
POT_4_W_P: J14.12, RV5.2, RV10.2
POT_ALG: A1.21, C8.1, J11.7
POT_ALG_P: J14.7, RV1.2, RV6.2
RESET: A1.8, Q1.3, R7.2
RES_LED: A1.7, R9.2
SCL: A1.24, J10.3
SDA: A1.23, J10.4
SEQ_OUT: A1.9, D14.1, R13.2, R14.2

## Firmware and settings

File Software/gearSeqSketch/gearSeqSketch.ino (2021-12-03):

/* G.E.A.R. sequencer Arduino sketch

   Rich Holmes 2021 CC0 1.0

   Portions drawn from 
   https://github.com/katspaugh/arduino-modular-synth/blob/master/arduino-euclid/arduino-euclid.ino
   (No stated license)

 */

#define OLED    1        // Nonzero to use OLED
#define FLIPPED 1        // Nonzero to flip display vertically (yellow
//                       // stripe at bottom)
#define SERIAL  0        // Nonzero to use serial monitor
#define MAX_PERIOD  32   // Can be reduced; increasing would require
//                       // significant changes
#define DEBOUNCEMILLIS 5 // For button debouncing, wait this long before
//                       // handling any new button presses.
//                       // 5 ms isn't much but it seems to handle the
//                       // bouncing on my switch, increase it to 10 or
//                       // 20 if needed with yours

#define NALGO 4          // Number of algorithms (other than None)

#include <assert.h>   // for assert macro

#if defined __AVR__   // use DirectIO library for fast digital read/write
#include <DirectIO.h> // --> https://github.com/mmarchetti/DirectIO.git
#endif

#if OLED
#include <U8g2lib.h>  // library for drawing to OLED
U8X8_SSD1306_128X64_NONAME_HW_I2C u8x8;  // object for OLED control
#endif

typedef unsigned short int param;
typedef char stateindex;

#define CLOCK_PIN         2
#define CLOCK_LED_PIN     3
#define RESET_LED_PIN     4
#define RESET_IN_PIN      5
#define SEQ_OUT_PIN       6
#define PER_OUT_PIN       7
#define DISP_BLANK_PIN    8

#define ALG_POT  A2
#define CV1_POT  A6
#define CV2_POT  A3
#define CV3_POT  A1
#define CV4_POT  A0

// Set up DirectIO

volatile InputLow<CLOCK_PIN>      i_clock (false);
InputLow<RESET_IN_PIN>            i_reset (false);
Input<DISP_BLANK_PIN>             i_disp_blank (true); // internal pullup on
volatile Output<CLOCK_LED_PIN>    o_clock;
Output<RESET_LED_PIN>             o_reset;
volatile Output<SEQ_OUT_PIN>      o_seq;
volatile Output<PER_OUT_PIN>      o_per;

// current algorithm in use and requested next algorithm
volatile unsigned short int curAlgo = 0;
volatile unsigned short int reqAlgo = 0;

// Potentiometers

char potlist[5] = {ALG_POT, CV1_POT, CV2_POT, CV3_POT, CV4_POT}; // alg first, then params pots

enum change {noChange, someChange, specialChange};

param lastPotState[5] = {9999, 9999, 9999, 9999, 9999};
long lastChangeTime = -999999;

// Sequence control
volatile int counter = -1;            // Current step #
int lastClockTime = 0;                // When last clock occurred
volatile bool clockState = false;     // True if clock pulse high
volatile bool lastClockState = false; // old clockState value
bool lastResetState = false;          // old reset value
volatile bool changeParAct = false;   // need to change actual parameters or algorithm

// parReq is requested values for next parameters.
// parPend is requested values modified by constraints, to go into use at
// start of next period.
// parAct is actual parameter values in use.

param parReq[4] = {9999, 9999, 9999, 9999};           // requested values
volatile param parPend[4] = {9999, 9999, 9999, 9999}; // constrained values pending
volatile param parAct[4];                             // actual current values
volatile long statesPend;                             // bits for the pending pattern
volatile long statesAct;                              // bits for the current pattern

// Display control
bool displayPend = false;        // display pending, not actual, parameters
bool displayBlank = false;       // don't display anything
volatile bool doDisplay = false; // update the display when you get a chance

// Forward declarations

int gcd (int a,int b);
void checkReset();
void SetupThisPeriod();
void onClockOn();
void onClockOff();
void tick();
void setup();
void loop();

//============================================================
//
// Main algorithm class and derivatives
//
//============================================================

class Algo
{
  // Implements a sequence-creating algorithm, its parameters, and
  // methods relating to it
  
 public:
  Algo() {Setup();}
  virtual void Setup();                        // Set up a new Algo object
  change checkPots();                          // Read the pots and note changes
  param PotToParam(int i);                     // Convert pot to parameter
  virtual param paramConstrain (int i, param p0, param p1, param p2, param p3);
  //                                           // Constrain parameter values
  void DisParams();                            // OLED display
  void UpdatePars();                           // Set requested params
  virtual void SetParPend();                   // Set constrained params
  virtual void SetStates() {statesPend = 0;}   // Set the trigger pattern
  bool GetState(stateindex i, long theStates = -999, param thePeriod = 0, param theOffset = 0);
  //                                           // Read the trigger pattern
  virtual param Period() const {return parAct[0];}
  virtual param PeriodPend() const {return parPend[0];}
  virtual param Offset() const {return parAct[3];}
  virtual param OffsetPend() const {return parPend[3];}
  String algName;               // Name of this algorithm
  String parName[4];            // Names of four parameters
  param parMin[4];              // Minimum for requested parameter value
  param parMax[4];              // Maximum for requested parameter value
  short unsigned int delta[5];  // pot range corresponding to change
  //                            // of algo or parameter
};

//============================================================

class GapAlgo: public Algo
{
  // Gap algorithm
  
 public:
  GapAlgo() {Setup();}
  void Setup();
  void SetStates();
  param paramConstrain (int i, param p0, param p1, param p2, param p3);
  void SetParPend();
};

//============================================================

class EuclidAlgo: public Algo
{
  // Euclidean algorithm
  
 public:
  EuclidAlgo() {Setup();}
  void Setup();
  void SetStates();
};

//============================================================

class ADCAlgo: public Algo
{
  // ADC algorithm
  
 public:
  ADCAlgo() {Setup();}
  void Setup();
  void SetStates();
  param paramConstrain (int i, param p0, param p1, param p2, param p3);
};

//============================================================

class RandAlgo: public Algo
{
  // Random algorithm
  
 public:
  RandAlgo() {Setup();}
  void Setup();
  void SetStates();
};

//============================================================

Algo* algoList[5];  // Vector of pointers to singleton algorithms:
//                           // None, Gap, Euclidean, ADC, Random

//============================================================

void Algo::Setup()
{
  algName = "None"; 
  parName[0] = "Per  "; // 5 chars
  parName[1] = "-N/A-";
  parName[2] = "-N/A-";
  parName[3] = "-N/A-";
  parMin[0] = 2;
  parMax[0] = MAX_PERIOD;
  parMin[1] = 0;
  parMax[1] = MAX_PERIOD;
  parMin[2] = 0;
  parMax[2] = 31;
  parMin[3] = 0;
  parMax[3] = MAX_PERIOD-1;
  // Significant pot change is width corresponding to change of parameter
  delta[0] = int(1024./(NALGO+1));
  for (int i = 0; i < 4; ++i)
    delta[i+1] = int(1024./(parMax[i]-parMin[i]+1));
}

//==============================

change Algo::checkPots()
{
  // Read pots and store new values if changed enough
  // If anything changed return someChange, otherwise noChange
  // unless only change was smallish change in ADC algo param 2
  // then return specialChange
  
  change whatChanged = noChange;
  bool onlySmallADCValChange = true;
  for (int ipot = 0; ipot < 5; ++ipot)
    {
      int potState = analogRead (potlist[ipot]);
      int ch = abs(int(potState)-int(lastPotState[ipot]));
      if (ch < delta[ipot])
	continue;
      lastPotState[ipot] = potState;
      if (reqAlgo != 3 || ipot != 2 || ch > 10)
	onlySmallADCValChange = false;
      whatChanged = someChange;
    }
  if (whatChanged == someChange && onlySmallADCValChange)
    return specialChange;
  else
    return whatChanged;
}

//==============================

param Algo::PotToParam(int i)
{
  // Map pot value to parMin..parMax
  // i == -1 for algorithm pot, 0-3 for parameter pots

  assert (i >= -1 && i < 4);
  param v = lastPotState[i+1];
  if (i == -1) // algorithm pot
    return param(float(v)/(1024./(NALGO+1))); // 0 to NALGO
  else
    return param(float(v)/(1024./(parMax[i]-parMin[i]+1))+parMin[i]);
}

//==============================

param Algo::paramConstrain (int i, param p0, param p1, param p2, param p3)
{
  // Constrain the ith requested parameter value, given value of it
  // and other three; this is used as the pending value of that parameter
  
  switch (i)
    {
    case 0:
      return constrain (p0, parMin[0], parMax[0]);
      break;
    case 1:
      return constrain (p1, parMin[1], p0);
      break;
    case 2:
      return constrain (p2, parMin[2], parMax[2]);
      break;
    case 3:
      return constrain (p3, parMin[3], p0-1);
      break;
    }
}

//==============================

void Algo::DisParams ()
{
  // Display algorithm, parameters, and trigger pattern on OLED
  // and/or serial monitor
  
  String d_algName;
  String d_parName[4];
  param d_par[4];
  long d_states;
  int d_period;
  int d_offset;
  char* xchar = "X";
  char* dotchar = ".";
  char* ochar = "O";
  char* dashchar = "-";
  char* d_on;
  char* d_off;

  // collect the data to be shown
  
  if (displayPend)
    {
      // For pending parameters display (while a pot is being changed)
      
      d_algName = algoList[reqAlgo]->algName;
      for (int ip = 0; ip < 4; ++ip)
	{
	  d_parName[ip] = algoList[reqAlgo]->parName[ip];
	  d_par[ip] = parPend[ip];
	}
      d_states = statesPend;
      d_period = PeriodPend();
      d_offset = OffsetPend();
      d_on = xchar;
      d_off = dotchar;
    }
  else
    {
      // For actual parameters display (while things are static)
      
      d_algName = algoList[curAlgo]->algName;
      for (int ip = 0; ip < 4; ++ip)
	{
	  d_parName[ip] = algoList[curAlgo]->parName[ip];
	  d_par[ip] = parAct[ip];
	}
      d_states = statesAct;
      d_period = Period();
      d_offset = Offset();
      d_on = ochar;
      d_off = dashchar;
    }

#if OLED

  // OLED update

  // Top line, algorithm name and "*" for pending display
  String str;
  char line[32];
  String top = d_algName + (algoList[reqAlgo]->algName == d_algName ? "" :
			  String ("[")+
			  algoList[reqAlgo]->algName.substring(0,3)+String("]"));
  int c = (16-top.length())/2;
  top.toCharArray(line, 17);
  u8x8.clearLine (0);
  if (displayPend)
    u8x8.drawString (0, 0, "*");
  u8x8.drawString (c, 0, line);

  // Next four lines, parameters — actual or pending — and requested
  // values if different
  char l = 1;
  for (int ip = 0; ip < 4; ++ip)
    {
      u8x8.clearLine (l);
      d_parName[ip].toCharArray(line, 6);
      u8x8.drawString (0, l, line);
      if (d_parName[ip] != "-N/A-")
	{
	  str = String(d_par[ip]);
	  while (str.length() < 4)
	    str = String(" ")+str;
	  str.toCharArray(line, 5);
	  u8x8.drawString (6, l, line);
	  
	  if (d_par[ip] != parReq[ip])
	    {
	      str = String(parReq[ip]);
	      str = String("[") + str + String("]");
	      str.toCharArray(line, 7);
	      u8x8.drawString (10, l, line);
	    }
	}
      ++l;
    }

  // Clear the following lines
  while (l < 8)
    u8x8.clearLine (l++);

  // Last one or two lines are the trigger pattern
  l = d_period < 17 ? 7 : 6;
  c = 0;
  for (int i = 0; i < d_period; ++i)
    {
      u8x8.drawString (c++, l, GetState (i, d_states, d_period, d_offset) ? d_on : d_off);
      if (c == 16)
	{
	  c = 0;
	  l++;
	}
    }

#endif
#if SERIAL
  // Print parameters and sequence to serial monitor

  // Name and "*" for pending display
  if (displayPend)
    Serial.print ("* ");
  Serial.print (d_algName);
  if (algoList[reqAlgo]->algName != d_algName)
    Serial.print (String ("[")+algoList[reqAlgo]->algName.substring(0,3)+String("]"));
  Serial.print (" ");

  // Parameters — actual or pending — and requested values if
  // different
  for (int ip = 0; ip < 4; ++ip)
    {
      Serial.print (d_parName[ip]);
      Serial.print (" ");
      if (d_parName[ip] == "-N/A-")
      	continue;
      Serial.print (d_par[ip]);
      if (d_par[ip] != parReq[ip])
      	{
      	  Serial.print (" [");
      	  Serial.print (parReq[ip]);
      	  Serial.print ("]");
      	}
      Serial.print (" ");
    }
  Serial.println();

  // Trigger pattern
  for (int i = 0; i < d_period; ++i)
    Serial.print (GetState (i, d_states, d_period, d_offset) ? d_on : d_off);
  Serial.println();
#endif

  doDisplay = false;
}

//==============================

void Algo::UpdatePars()
{
  // Get values for requested parameters, and if any have changed,
  // update the pending parameters (and algorithm) and trigger pattern

  bool changed = false; // if any par different than last time
  bool changedNotOffset = false; // if any of pars 0-3 different

  for (int ip = 0; ip < 4; ++ip)
    {
      param newPar = PotToParam(ip);
      if (newPar != parReq[ip])
      {
	parReq[ip] = newPar;
	changed = true;
	if (ip != 3)
	  changedNotOffset = true;
      }
    }
  if (changed)
    {
      SetParPend();
      // New states if change other than offset
      if (changedNotOffset)
	SetStates ();
    }
}

//==============================

void Algo::SetParPend()
{
  // Set pending parameters from constrained requested parameters
  
  parPend[0] = paramConstrain (0, parReq[0], parReq[1], parReq[2], parReq[3]);
  // Other params may be constrained by constrained period
  parPend[1] = paramConstrain (1, parPend[0], parReq[1], parReq[2], parReq[3]);
  parPend[2] = paramConstrain (2, parPend[0], parReq[1], parReq[2], parReq[3]);
  parPend[3] = paramConstrain (3, parPend[0], parReq[1], parReq[2], parReq[3]);
}

//==============================

bool Algo::GetState(stateindex index, long theStates, param thePeriod, param theOffset)
{
  // Get state value with offset. Use specified theStates, thePeriod, and
  // theOffset, unless theStates is -999, then use actual current ones.

  // Pettern is stored as a 32 bit word, one bit per sequencer step
  
  if (theStates == -999)
    {
      theStates = statesAct;
      thePeriod = Period();
      theOffset = Offset();
    }
  
  assert (thePeriod <= MAX_PERIOD);
  stateindex stepIdx = (index + (thePeriod-theOffset)) % thePeriod;
  return ((theStates & (0x80000000 >> stepIdx)) != 0);
}

//============================================================

void GapAlgo::Setup()
{
  Algo::Setup();
  algName = "Gap";
  parName[1] = "Trigs"; // 5 chars
  parName[2] = "Gener";
  parName[3] = "Offs ";
  parMin[2] = 1;
  parMax[2] = MAX_PERIOD/2;
  delta[3] = int(1024./(parMax[2]-parMin[2]+1));
}

//==============================

param GapAlgo::paramConstrain (int i, param p0, param p1, param p2, param p3)
{
  // Constrain the ith requested parameter value, given value of it
  // and other three; this is used as the pending value of that parameter
  
  if (i == 1)
    return constrain (p1, parMin[1], p0+p2 > 0 ? p0/gcd(p0,p2) : p0);
  else if (i == 2)
    return constrain (p2, parMin[2], p0/2);
  else
    return Algo::paramConstrain (i, p0, p1, p2, p3);
}

//==============================

void GapAlgo::SetParPend()
{
  // Set pending parameters from constrained requested parameters
  
  parPend[0] = paramConstrain (0, parReq[0], parReq[1], parReq[2], parReq[3]);
  // Other params may be constrained by constrained period
  parPend[2] = paramConstrain (2, parPend[0], parReq[1], parReq[2], parReq[3]);
  // Triggers may be further constrained by constrained generator
  parPend[1] = paramConstrain (1, parPend[0], parReq[1], parPend[2], parReq[3]);
  parPend[3] = paramConstrain (3, parPend[0], parReq[1], parPend[2], parReq[3]);
}

//==============================

void GapAlgo::SetStates()
{
  // Set the trigger pattern using the gap algorithm
  // Pettern is stored as a 32 bit word, one bit per sequencer step
  
  if (parPend[1] == 0)
    statesPend = 0x0;
  else
    {
      stateindex index = 0;
      statesPend = 0x80000000;

      for (int var = 1; var < parPend[1]; ++var)
	{
	  index = (index + parPend[2]) % parPend[0];
	  statesPend |= 0x80000000 >> index;
	}
    }
}

//============================================================

void EuclidAlgo::Setup()
{
  Algo::Setup();
  algName = "Euclidean";
  parName[1] = "Trigs"; // 5 chars
  parName[3] = "Offs ";
}

//==============================

void EuclidAlgo::SetStates()
{
  // Set the trigger pattern using the Euclidean algorithm
  // Pettern is stored as a 32 bit word, one bit per sequencer step

  // Algorithm source:
  // https://www.computermusicdesign.com/simplest-euclidean-rhythm-algorithm-explained/

  assert (parPend[0] <= MAX_PERIOD);
  int bucket = 0;
  statesPend = 1;

  for (stateindex var = 0; var < parPend[0]; ++var)
    {
      bucket += parPend[1];
      if (bucket >= parPend[0])
	{
	  bucket -= parPend[0];
	  statesPend |= 0x80000000 >> var;
	}
    }
}

//============================================================

void ADCAlgo::Setup()
{
  Algo::Setup();
  algName = "ADC";
  parName[1] = "Value"; // 5 chars
  parName[3] = "Offs ";
  parMin[1] = 0;
  parMax[1] = 1023;
  delta[2] = int(1024./(parMax[1]-parMin[1]+1))+2; /// Inflate to stop churn for now
}

//==============================

param ADCAlgo::paramConstrain (int i, param p0, param p1, param p2, param p3)
{
  // Constrain the ith requested parameter value, given value of it
  // and other three; this is used as the pending value of that parameter
  
  if (i == 0)
    return constrain (p0, parMin[1], 10);
  else if (i == 1)
    return constrain (p1, parMin[1], parMax[1]);
  else
    return Algo::paramConstrain (i, p0, p1, p2, p3);
}

//==============================

void ADCAlgo::SetStates()
{
  // Set the trigger pattern using the gap algorithm
  // Pettern is stored as a 32 bit word, one bit per sequencer step

  statesPend = long(parPend[1]) << 22;  // OK, that was easy
}

//============================================================

void RandAlgo::Setup()
{
  Algo::Setup();
  algName = "Random";
  parName[1] = "Trigs"; // 5 chars
  parName[2] = "Throw";
  parName[3] = "Offs ";
}

//==============================

void RandAlgo::SetStates()
{
  // Set the trigger pattern using the ramdom algorithm
  // Pettern is stored as a 32 bit word, one bit per sequencer step

  // Make a list of all step numbers, pick one at random and set it to
  // 1 in state; move it to the end of the list and repeat with that
  // last entry excluded; et cetera

  assert (parPend[0] <= MAX_PERIOD);
  statesPend = 0;
    
  int ldeck = parPend[0];  
  stateindex deck[ldeck];
  
  for (int id = 0; id < ldeck; ++id)
    deck[id] = id;

  for (int var = 0; var < parPend[1]; ++var)
    {
      int id = random(ldeck);
      statesPend |= 0x80000000 >> deck[id];
      ldeck -= 1;
      int tmp = deck[ldeck];
      deck[ldeck] = deck[id];
      deck[id] = tmp;
    }
}

//============================================================

int gcd (int a,int b)
{
  // Greatest common divisor (the REAL Euclidean algorithm!) for
  // Gap sequence trigger parameter constraints
  
  int R;
  while ((a % b) > 0)
    {
      R = a % b;
      a = b;
      b = R;
    }
  return b;
}

//==============================

void checkReset()
{
  // See if we need to reset this sequence

  bool reset = i_reset.read();
  if (reset == lastResetState) return;
  lastResetState = reset;
  if (reset)
    counter = -1; // will be zero next clock pulse
  o_reset.write(reset);
}

//==============================

void SetupThisPeriod()
{
  // Set things for this period — copying pending values to actual
  curAlgo = reqAlgo;
  for (int i = 0; i < 4; ++i)
    parAct[i] = parPend[i];
  statesAct = statesPend;
}

//==============================
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
void loop()
{
  // Examine the pots and see if there's been a significant change
  change whatChanged = algoList[reqAlgo]->checkPots();
  if (whatChanged != noChange)
    {
      if (whatChanged == someChange)
	{
	  // Turn on pending values display and update change time only
	  // if change was NOT just ADC algo channel 2 by a small amount
	  // (because that one has 10 significant bits and they can
	  // fluctuate if there's noise)
	  displayPend = true;
	  lastChangeTime = millis();
	}
      doDisplay = true;
      // Check for new algorithm
      unsigned short int newAlgo = constrain (algoList[curAlgo]->PotToParam(-1), 0, NALGO);
      if (newAlgo != reqAlgo)
	reqAlgo = newAlgo;

      // Update the requested parameters, and remind ourself to change
      // actual parameters next sequencer period
      algoList[reqAlgo]->UpdatePars();
      changeParAct = true;
    }

  // Did someone say RESET?
  checkReset();

  // Stop displaying pending values after changes stop for a while
  if (displayPend && (millis() - lastChangeTime > 2000))
    {
      displayPend = false;
      doDisplay = true;
    }

  // If the display blanking switch has changed, change the boolean
  // and if it's now on, blank the display; if it's off, trigger display.
  // (This affects serial output too.)
  bool dbValue = i_disp_blank.read();
  if (dbValue != displayBlank)
    {
      displayBlank = dbValue;
      if (displayBlank)
#if OLED
	u8x8.setPowerSave(true);
#endif
      else
	{
	  doDisplay = true;
#if OLED
	  u8x8.setPowerSave(false);
#endif
	}
    }

  // Update the display if needed
  if (doDisplay && !displayBlank)
      algoList[curAlgo]->DisParams();      
}

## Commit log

2021-09-29 Initial version
    [gearseq.kicad_pcb, gearseq.sch, gearseq_panel.kicad_pcb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]
2021-09-29 Fix up sketch, add push buttons
    [gearseq.kicad_pcb, gearseq.sch, panel_pcb.sch]
2021-10-03 Panel design
    [gearseq_panel.kicad_pcb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]
2021-10-31 Add 15 mm pot option; BOM
    [gearseq.kicad_pcb, gearseq.sch, panel_pcb.sch]
2021-10-31 Use ao_symbols
    [gearseq.kicad_pcb, gearseq.sch, panel_pcb.sch]
2021-11-04 Revise clock and reset inputs, shift board positions
    [gearseq.kicad_pcb, gearseq.sch, panel_pcb.sch]
2021-11-06 Fix push button holes; develop and debug software
    [gearseq_panel.kicad_pcb]
2021-11-08 Change pot values; README updates; lots of sketch development
    [panel_pcb.sch]
2021-11-08 Add capacitors
    [gearseq.kicad_pcb, gearseq.sch]
2021-11-09 Use DirectIO and move clock handling into interrupt
2021-11-09 Add display blanking switch, stop Period output when None algo, flip OLED
    [gearseq.kicad_pcb, gearseq.sch, panel_pcb.sch]
2021-11-11 Display tweak, RL comment
    [gearseq.sch]
2021-11-12 Final pre fab tweaks, correct oversize LED footprint
    [gearseq.kicad_pcb, gearseq.sch, gearseq_panel.kicad_pcb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]
2021-11-13 Update docs, generate Gerbers, change PCB hole to notch
    [gearseq-B_Cu.gbr, gearseq-B_Mask.gbr, gearseq-B_SilkS.gbr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]
2021-11-15 Don't display pending for tiny ADC VALUE changes; handle TRIGS=0 correctly in GAP
    [gearSeqSketch.ino]
2021-12-03 Documentation updates
    [gearseq.sch]
2021-12-24 Current draw
